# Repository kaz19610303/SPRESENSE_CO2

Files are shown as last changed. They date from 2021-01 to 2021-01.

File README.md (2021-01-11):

# SPRESENSE_CO2
CO2,temperature and humidity sensores bord for SPRESENSE.

CPUボード  
[Sony SPRESENSE](https://developer.sony.com/ja/develop/spresense/)

使用センサー  
|センサー|メーカー|データシート
|:----|:----|:----|
| SGP30-2.5K | Sensirion | https://www.mouser.jp/datasheet/2/682/Sensirion_Gas_Sensors_SGP30_Datasheet-1843629.pdf |
| SHTC1 | Sensirion | https://www.mouser.jp/datasheet/2/682/Sensirion_Humidity_Sensors_SHTC1_Datasheet-1511754.pdf |

プロラム開発環境  
[Spresense Arduino](https://developer.sony.com/develop/spresense/docs/arduino_set_up_ja.html)

参考  
[Sony Spresense LTE拡張ボードで温湿度、eCO2、TVOCのデータをCloud(Thingspeak)にアップロード](https://qiita.com/kaz19610303/items/e653e129437775d22272)

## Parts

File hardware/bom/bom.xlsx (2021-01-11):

Parts | Qty | Value | Device | Package | Description | MANUFACTURER_NAME | MANUFACTURER_PART_NUMBER | MOUSER_PART_NUMBER | PRICE-STOCK
C2, C3 | 2 | 0.1uF | CERAMIC-100NF-50V-10%-X7R(0603) | 0603 | 0.1uF ceramic capacitors | Yageo | CC0603KRX7R9BB104 | 603-CC603KRX7R9BB104 | https://www.mouser.jp/ProductDetail/Yageo/CC0603KRX7R9BB104/
C1 | 1 | 10uF | CERAMIC-10UF-6.3V-20%-X5R(0603) | 0603 | 10.0uF ceramic capacitors | Yageo | CC0603MRX5R5BB106 | 603-CC603MRX5R5BB106 | https://www.mouser.jp/ProductDetail/Yageo/CC0603MRX5R5BB106
J1, J2 | 2 | 4p-2.54 | DIP-BLACK-FEMALE-HEADER-VERT(4P-2.54) | H4-2.54 | 320030017 |  |  |  | https://www.switch-science.com/catalog/6108/
IC2 | 1 | SGP30-2.5K | SGP30-2.5K | SON80P245X245X90-7N | Air Quality Sensors Multi-Pixel SGP Gas Sensor | Sensirion | SGP30-2.5k | 403-SGP30-2.5K | https://www.mouser.jp/ProductDetail/Sensirion/SGP30-25k?qs=HXFqYaX1Q2xVSiHQfO6Ujg==
IC1 | 1 | SHTC1 | SHTC1 | SON100P200X200X7500-5N | Temperature Humidity Sensor Digital DFN4 Sensirion SHTC1 Temperature & Humidity Sensor 4-Pin DFN, -40 +125 C | Sensirion | SHTC1 | 403-SHTC1 | https://www.mouser.jp/ProductDetail/Sensirion/SHTC1?qs=Mn9EN1AKrqQgZpobGSD1iQ==

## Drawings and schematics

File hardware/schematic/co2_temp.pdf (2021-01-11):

A

A

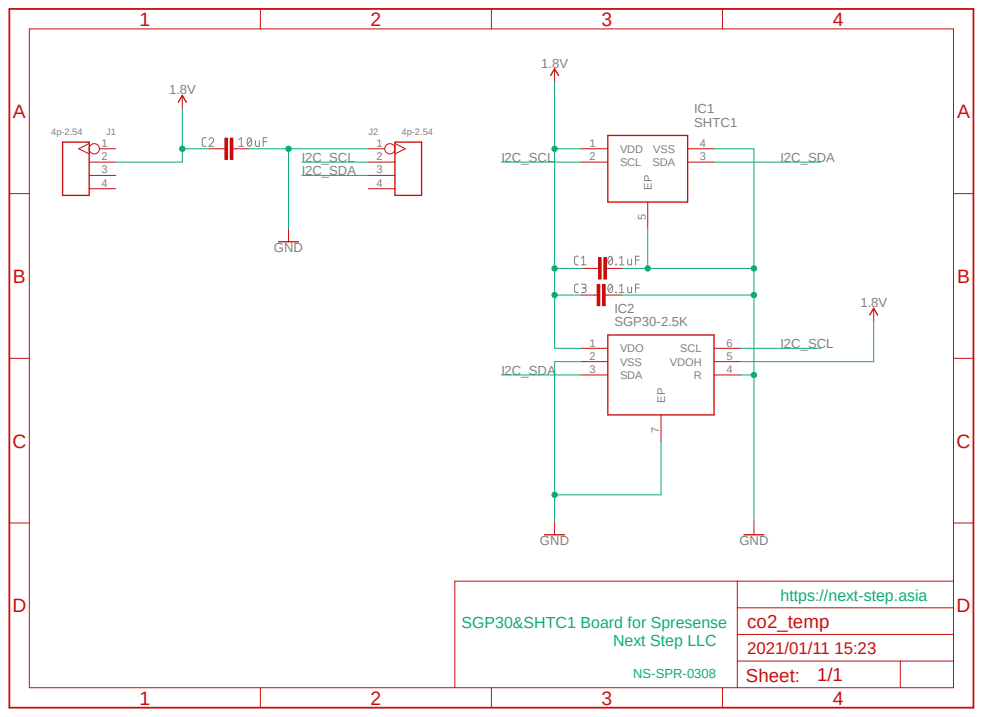
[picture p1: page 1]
SGP30-2.5K; GND; SHTC1; VDO 1; VSS 2; SDA 3; 7 SCL 6 VDOH 5 R; VDD 1; SCL 2; 5 VSS 4 SDA 3; I2C_SCL; I2C_SDA; Sheet:; co2_temp; https://next-step.asia; NS-SPR-0308

SGP30&SHTC1 Board for Spresense

Next Step LLC

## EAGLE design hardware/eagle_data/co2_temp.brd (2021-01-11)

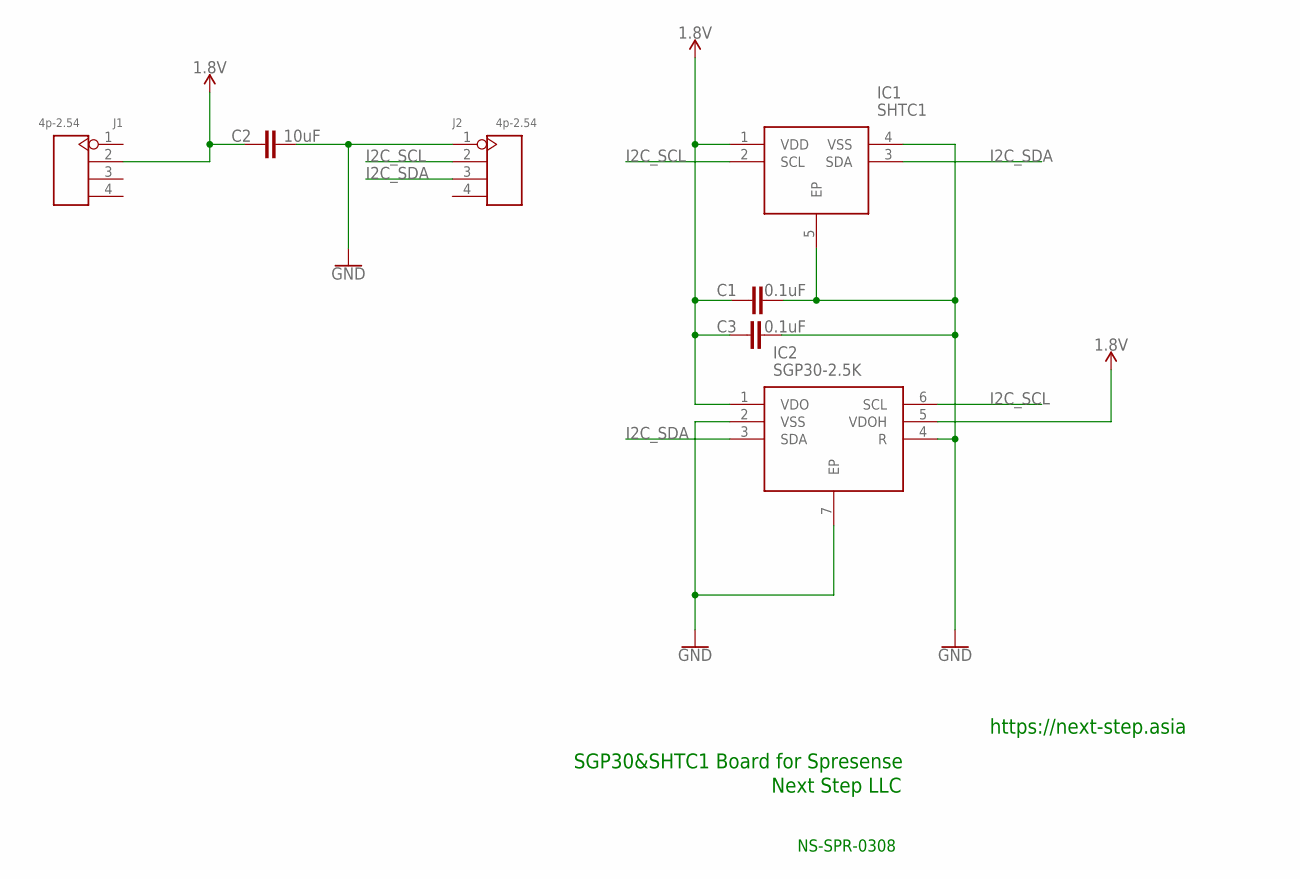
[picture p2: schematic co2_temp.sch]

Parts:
C1, C3: 0.1uF; 0603
C2: 10uF; 0603
IC1: SHTC1; SON100P200X200X7500-5N
IC2: SGP30-2.5K; SON80P245X245X90-7N
J1, J2: 4p-2.54; H4-2.54

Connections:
1.8V: C1.1, C2.1, C3.1, IC1.1 (VDD), IC2.1 (VDO), IC2.5 (VDOH), J1.2
GND: C1.2, C2.2, C3.2, IC1.4 (VSS), IC1.5 (EP), IC2.2 (VSS), IC2.4 (R), IC2.7 (EP), J2.1
I2C_SCL: IC1.2 (SCL), IC2.6 (SCL), J2.2
I2C_SDA: IC1.3 (SDA), IC2.3 (SDA), J2.3

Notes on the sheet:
SGP30&SHTC1 Board for Spresense
Next Step LLC
https://next-step.asia
NS-SPR-0308

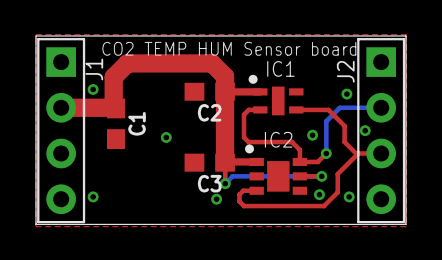
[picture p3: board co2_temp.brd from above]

Board: 2 copper layers, 20.6 x 10.5 mm, 7 parts (0 on the bottom side), 4 nets.

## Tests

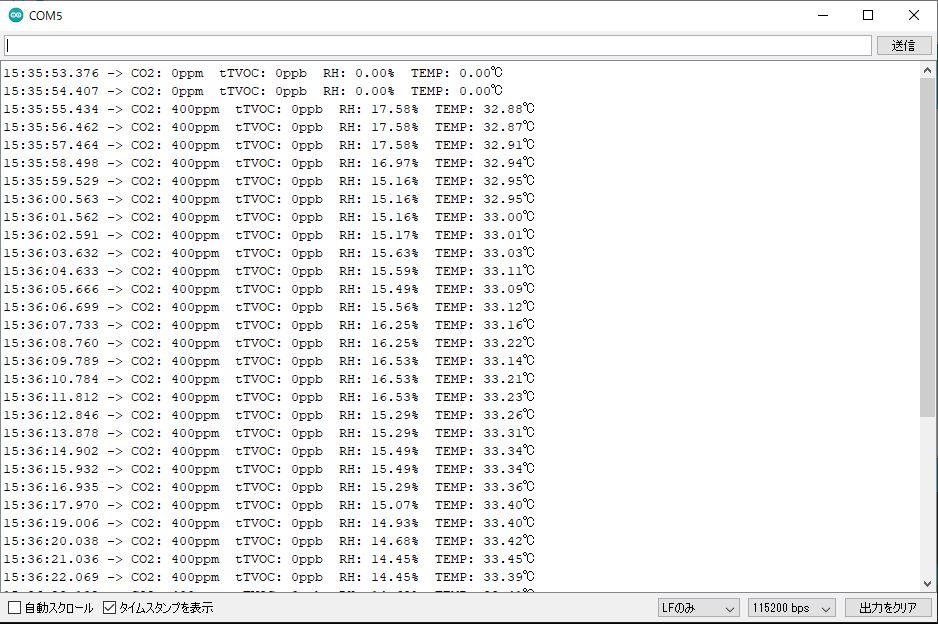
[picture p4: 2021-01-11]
Test_Program/SPRESENSE_CO2_terminal_log.JPG

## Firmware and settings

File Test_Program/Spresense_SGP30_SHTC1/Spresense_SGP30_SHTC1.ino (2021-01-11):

/*
  Library for the Sensirion SGP30 Indoor Air Quality Sensor
  By: Ciara Jekel
  SparkFun Electronics
  Date: June 28th, 2018
  License: This code is public domain but you buy me a beer if you use this and we meet someday (Beerware license).

  SGP30 Datasheet: https://cdn.sparkfun.com/assets/c/0/a/2/e/Sensirion_Gas_Sensors_SGP30_Datasheet.pdf

  Feel like supporting our work? Buy a board from SparkFun!
  https://www.sparkfun.com/products/14813

  This example reads the sensors calculated CO2 and TVOC values
*/

#include "SparkFun_SGP30_Arduino_Library.h" // Click here to get the library: http://librarymanager/All#SparkFun_SGP30
#include <Wire.h>
#include <shtc1.h>
#include <stdlib.h>

SGP30 mySensor; //create an object of the SGP30 class
SHTC1 shtc1;

int compareFloat(const void*, const void*);
float get_median(const float*, uint8_t);

int compareFloat(const void* a, const void* b)
{
    int aNum = *(float*)a;
    int bNum = *(float*)b;

    if( aNum < bNum ){
        return -1;
    }
    else if( aNum > bNum ){
        return 1;
    }
    return 0;
}

float get_median(const float* array, uint8_t size)
{
    float median;

    // array のコピーを作って、ソートする
    float* array_copy = malloc(sizeof(float) * size);
    memcpy(array_copy, array, sizeof(float) * size);
    qsort(array_copy, size, sizeof(float), compareFloat);
    median = array_copy[size / 2];
    free(array_copy);
    return median;
}

void setup() {
  Serial.begin(115200);
  Wire.begin();
  //Initialize sensor
  if (mySensor.begin() == false) {
    Serial.println("No SGP30 Detected. Check connections.");
    while (1);
  }
  //Initializes sensor for air quality readings
  //measureAirQuality should be called in one second increments after a call to initAirQuality
  mySensor.initAirQuality();
}

void loop() {
  static float co2_arry[5]  = {0.0};
  static float tvoc_arry[5] = {0.0};
  static float temp_arry[5] = {0.0};
  static float hum_arry[5]  = {0.0};

  float co2,tvoc,temp,hum;
  uint8_t i;

  
  //First fifteen readings will be
  //CO2: 400 ppm  TVOC: 0 ppb
  //measure CO2 and TVOC levels
  mySensor.measureAirQuality();
  //measure TEMP and HUM levels
  shtc1.readSample();

  co2  = float(mySensor.CO2);
  tvoc = float(mySensor.TVOC);
  temp = shtc1.getTemperature();
  hum  = shtc1.getHumidity();

  for(i = 1 ; i < 5; i++){
    co2_arry[i-1]  = co2_arry[i];
    tvoc_arry[i-1] = tvoc_arry[i];
    temp_arry[i-1] = temp_arry[i];
    hum_arry[i-1]  = hum_arry[i];
  }
  co2_arry[4]  = co2;
  tvoc_arry[4] = tvoc;
  temp_arry[4] = temp;
  hum_arry[4]  = hum;
   
  Serial.print("CO2: ");
  Serial.print(get_median(co2_arry,5),0);
  Serial.print("ppm  tTVOC: ");
  Serial.print(get_median(tvoc_arry,5),0);
  Serial.print("ppb");

  Serial.print("  RH: ");
  Serial.print(get_median(hum_arry,5), 2);
  Serial.print("%  TEMP: ");
  Serial.print(get_median(temp_arry,5), 2);
  Serial.println("℃");

  delay(1000); //Wait 1 second

}

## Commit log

2020-11-17 hardware first commit
    [mh-z19b.brd, mh-z19b.sch]
2021-01-11 Test program,BOM
    [bom.xlsx, co2_temp.brd, co2_temp.sch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]

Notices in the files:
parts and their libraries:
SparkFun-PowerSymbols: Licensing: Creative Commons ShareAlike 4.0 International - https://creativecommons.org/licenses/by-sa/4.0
